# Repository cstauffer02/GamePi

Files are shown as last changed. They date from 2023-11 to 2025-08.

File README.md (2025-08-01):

# 🎮 GamePi

A portable handheld retro gaming console powered by a **Raspberry Pi Zero W**. The **GamePi** is designed as a low‑cost, DIY‑friendly device capable of running classic game console emulators with full physical controls, a compact display, and portable power.

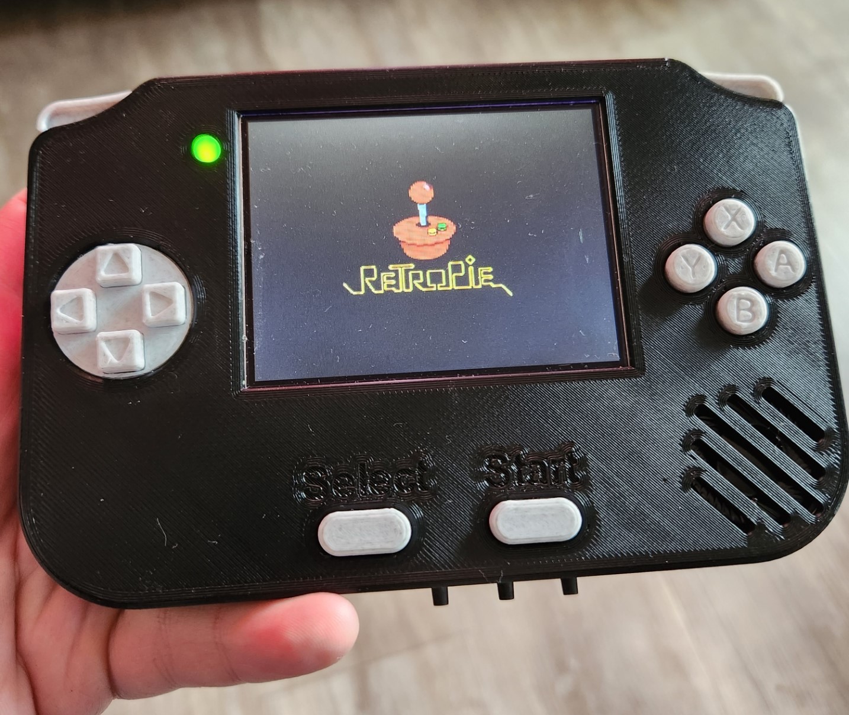
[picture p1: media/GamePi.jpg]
GamePi


🎥 [Watch the GamePi demo video](https://vimeo.com/1106315738?fl=pl&fe=sh)

---

## 🎯 Project Goals

1. **Design a portable handheld retro gaming console** that supports targeted retro console emulators with a complete control interface:
   - NES
   - Sega Genesis
   - SNES
   - Game Boy, Game Boy Color, Game Boy Advance
2. **Include all essential controls:**
   - Directional pad (D‑Pad)
   - A, B, X, Y buttons
   - R/L bumpers
   - Start & Select buttons
   - Mono audio with volume control
3. **Reuse already‑owned components from college program** where possible to keep costs low.
4. Keep the design **affordable** and **iterative** — the current revision is a working prototype, to be refined over time.

---

## 🛠 Design & Features

- **3.5‑inch LCD screen** for retro game visuals
- **Display settings interface** via 3 front‑mounted buttons
- **Mono audio** output with adjustable volume wheel
- **Portable** — powered by onboard AA batteries or external micro‑USB
- **Removable Raspberry Pi Zero W**
- **Accessible ports** — micro‑USB (power), USB (devices), and mini‑HDMI
- **Removable battery compartment cover**
- **Removable Pi cover** with convenient port cutouts

---

## 🧩 Hardware Overview

- **Main Processor:** Raspberry Pi Zero W
- **PCB:** Designed in Altium
- **Enclosure & Buttons:** Designed in Fusion 360
- **Display:** 3.5" LCD
- **Audio:** Mono speaker with volume control
- **Power:**
  - AA battery pack (portable mode)
  - External micro‑USB (bench power mode)

---

## 🖼 Enclosure & Assembly

The enclosure is designed for both ease of access and durability:
- Rear **battery cover** allows quick battery changes
- Rear **Raspberry Pi cover** enables Pi removal for other projects
- Pi connects to PCB via **female header rail** for tool‑free removal
- Port access slots in the Pi cover for power, USB devices, and HDMI

---

## 📜 Design Philosophy

This prototype intentionally uses **mixed component types** (axial + SMD resistors, etc.) for the sake of **component availability**:
> _Some unintuitive design choices may be noticed in the PCB files. For example, the use of both axial and SMD resistors. This stems from goal #3 — “Reuse already‑owned components from college program.” Some SMD components were not available during development, so axial/radial parts were substituted._

---

## 📂 Repository Structure

    GamePi/
    ├── Enclosure/          # Fusion 360 CAD models for case & buttons
    ├── PCB/                # Altium PCB design files
    ├── media/              # Images and demonstration video
    └── README.md 
---

## 🚀 Future Improvements

- Refine PCB layout for cleaner component selection
- Improve enclosure ergonomics
- Integrate rechargeable lithium battery + charging circuit
- Implement conductive silicon button pads for quieter buttons
- Add stereo audio support
- Explore Pi 4 CM for improved performance

---

## 👤 Author

**Cameron Stauffer**  
Electrical Project Engineer | Hardware & Embedded Systems Enthusiast  
[LinkedIn](www.linkedin.com/in/cameronstauffer)

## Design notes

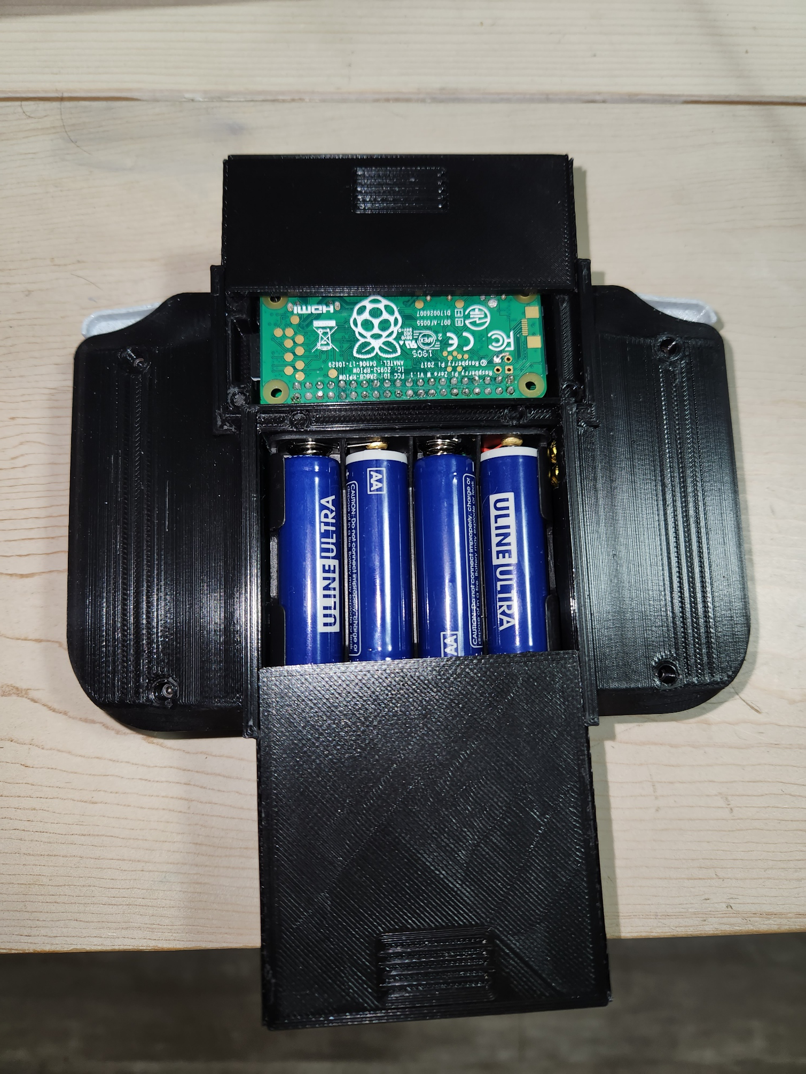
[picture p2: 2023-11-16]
media/GamePi_Removable_Covers.jpg

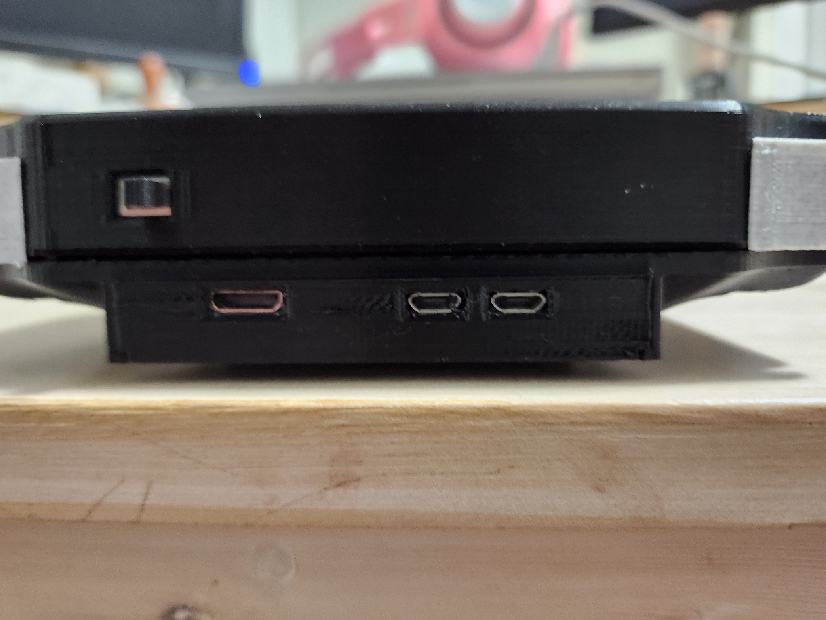
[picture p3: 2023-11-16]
media/GamePi_Top_IO.jpg

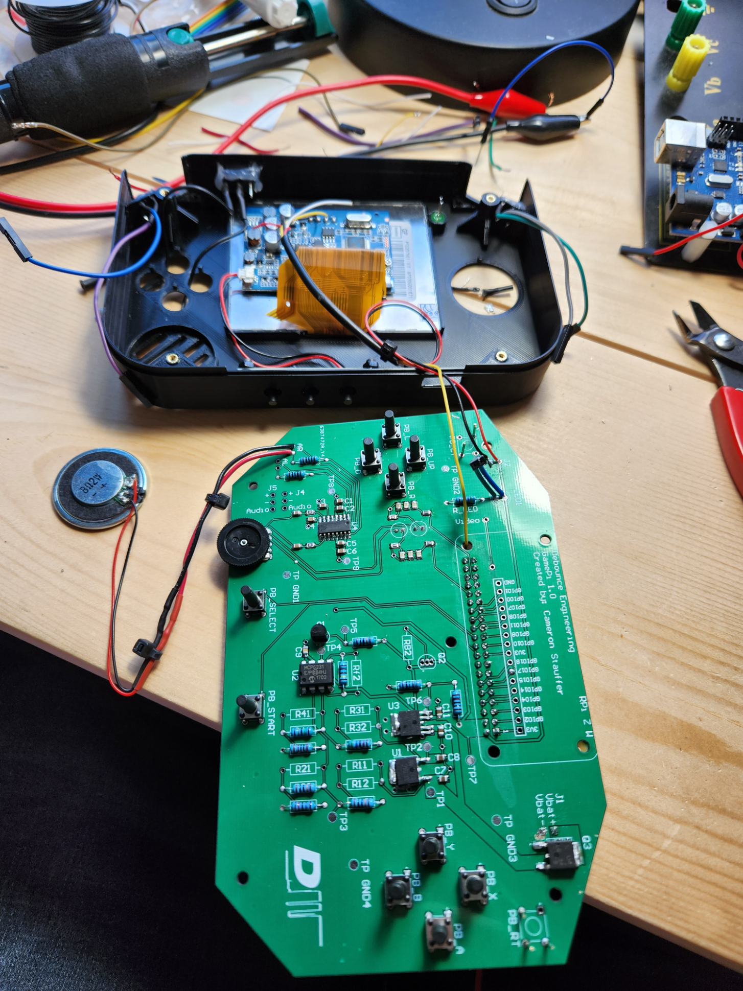
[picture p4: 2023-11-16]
media/populatingPCB.jpg

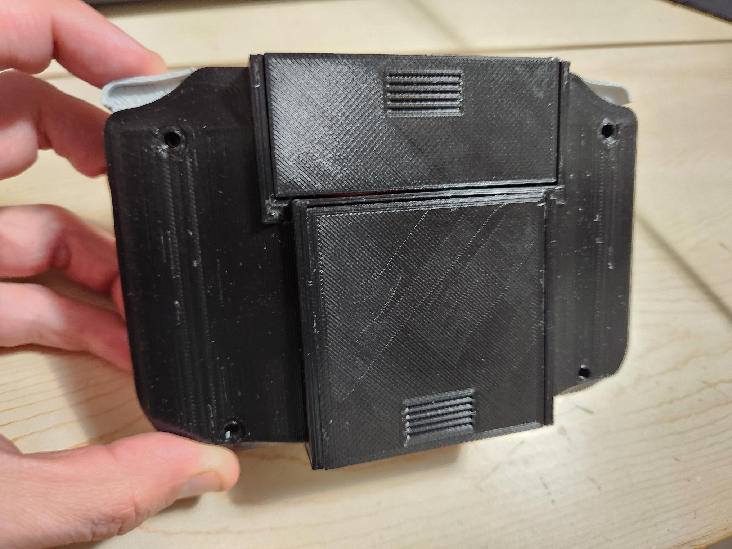
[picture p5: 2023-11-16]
media/GamePi_Rear.jpg

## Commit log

2023-04-24 Over discharge protection experiment results
    [Over Discharge Protection Circuit.xlsx]
2023-04-24 Component libraries and CAD files added to repository
2023-04-24 Schematics updated
    [Direction Pad(1).SchDoc, GamePi SCH LIB.SchLib, GamePi_SCHEMATIC.SchDoc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]
2023-08-30 Direction Pad circuit
    [Direction Pad.SchDoc]
2023-08-30 Schematic including buttons A, B, X, Y, LT, RT, START, SELECT
    [Buttons_SCHEMATIC.SchDoc]
2023-09-16 Renamed Direction Pad_SCHEMATIC file
    [Direction Pad(1).SchDoc, Direction Pad.SchDoc, Direction Pad_SCHEMATIC.SchDoc]
2023-09-16 Buttons A, B, X, Y, LT, RT, SELECT, START added to the project
    [Buttons_SCHEMATIC.SchDoc]
2023-09-16 Audio circuit added to the project
    [Audio_SCHEMATIC.SchDoc]
2023-09-16 Top level schematic changed - includes sub-circuits as schematic symbols
    [GamePi_SCHEMATIC.SchDoc]
2023-09-16 PCB LIB and SCH LIB updated, project file updated with structure
    [.PcbLib, .SchLib, GamePi SCH LIB.SchLib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]
2023-09-16 Over discharge protection circuit added to project
    [Over Discharge Protection_SCHEMATIC.SchDoc]
2023-11-16 Low-pass capacitors connected in series to allow for more precise filter tunning
    [Audio_SCHEMATIC.SchDoc]
2023-11-16 NPN BJT that sinks ENABLE signal now has axial base resistor
    [Over Discharge Protection_SCHEMATIC.SchDoc]
2023-11-16 PCB layout implements latest schematic changes - LP caps, base resistor, RPi net corrections
2023-11-16 RPi nets corrected with updated component
    [GamePi_SCHEMATIC.SchDoc]
2023-11-16 Updated RPi component and nets
    [GamePi.SCHLIB]
2023-11-16 GamePi schematic and PCB libraries updated
    [GamePi.SCHLIB]
2023-11-16 Project file updated with latest revision
    [GamePi.PrjPcb]
2023-11-16 Enclosure STEP file moved from PCB directory to Enclosure directory
